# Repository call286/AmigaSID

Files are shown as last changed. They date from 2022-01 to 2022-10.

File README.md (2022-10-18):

# AmigaSID Zorro II card

Board Render Front           |  Board Render Back
:-------------------------:|:-------------------------:
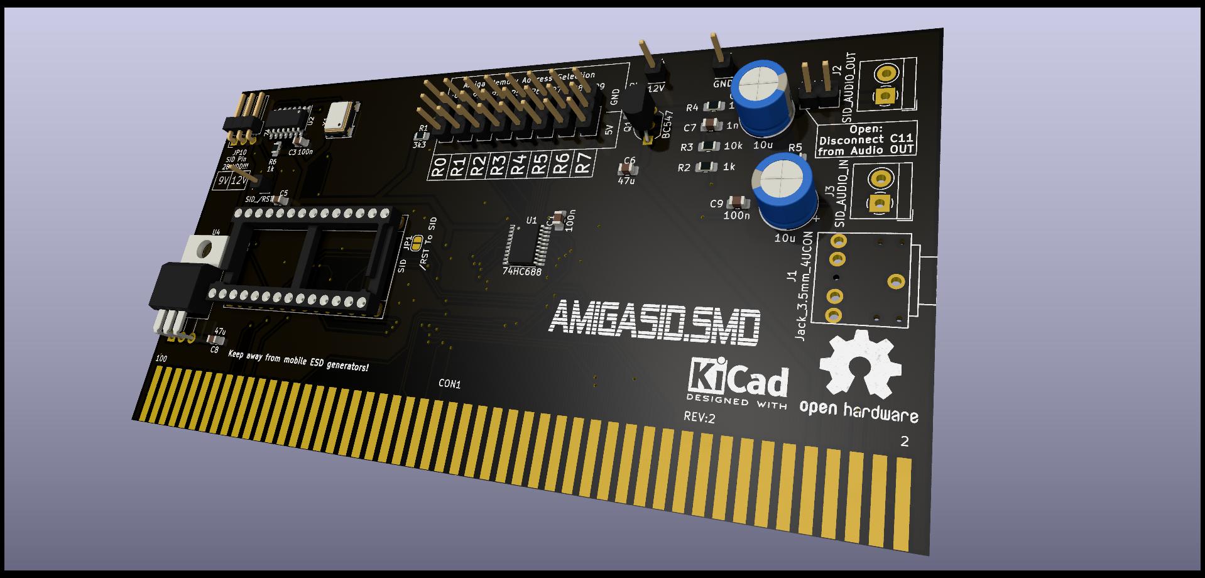
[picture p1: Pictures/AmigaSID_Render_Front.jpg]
Board Render Front
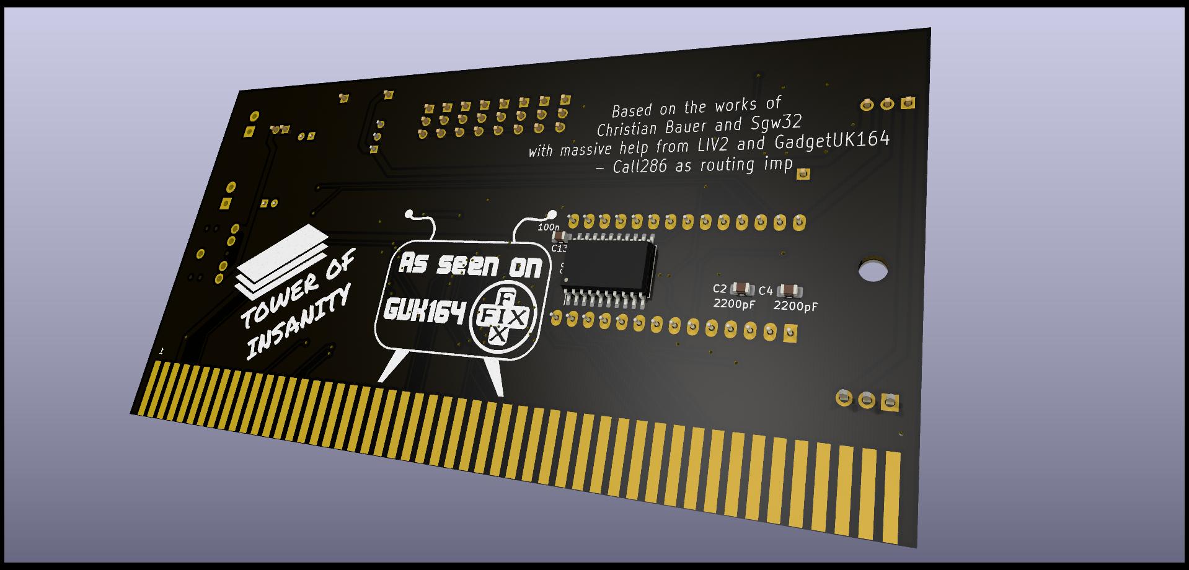
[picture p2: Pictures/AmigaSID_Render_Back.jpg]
Board Render Back
 | 

[Schematic PDF](Hardware/AmigaSID-schematic.pdf)

Forked from https://github.com/Sgw32/AmigaSID which forked from http://www.amibay.com/showthread.php?108629-Amiga-SID-player-for-Zorro-slot

Can't find the original thread on Amibay sadly, so i can't do full credits here.

## Changes

- Changed most of the components to SMD, major rerouting.
- Added 100k pull down resistor and 470pF capacitor to EXT_IN of SID like pointed out at the original schematics.
- Added 245 buffer to D0-D7 databus lines.
- Changed crystal to 7050 part.
- Tied Amiga /RST to RST of SID via solderjumper (default connected)
  - can be removed with a cut and be used at A4k with it's power LED connected to H1
- Added 8 jumpers (JP2-JP9) to set the memory address the SID can be accessed from the player side (needs patched player to use that address)
- Added filter caps to vcc lines of the IC's
- Changed audio connector to a more common type
- Moved filter caps closer to IC's
- Added logo
- Floating 74LS00 inputs tied to VCC
- Flipped polarity on C10 (SID_AUDIO_IN)
- Added jumper to disconnect audio out cap from output pins
  - instead you now can fit a little amp board like shown Gadgets video about the original version of the card
  - also added one GND and one 12V pin for powering the amp

Thanks to [LIV2](https://github.com/LIV2) and [GadgetUK](https://www.youtube.com/channel/UCRBWJ9JeJ3Q8ssn_ibii-Cg) for the help in this project.

Use at your own risk!!!
~~As of now (06.01.2021) i haven't tested that, not even ordered boards!~~
Boards were kindly provided by SparxUK - Thanks mate!
The boards worked fine on my A500 with a Zorro2 adapter and a NanoSwinSID.

## Jumper setting

The bank of jumpers on top of the card (JP2-JP9) is used to set the memory address used by the card and the players.

Jumper setting for EE range:

| Jumper  | Setting |
| :---:|:---: |
| JP2 |  1-2 (LOW) |
| JP3 |  2-3 (HIGH)  |
| JP4 |  2-3 (HIGH)  |
| JP5 |  2-3 (HIGH)  |
| JP6 |  1-2 (LOW) |
| JP7 |  2-3 (HIGH)  |
| JP8 |  2-3 (HIGH)  |
| JP9 |  2-3 (HIGH)  |

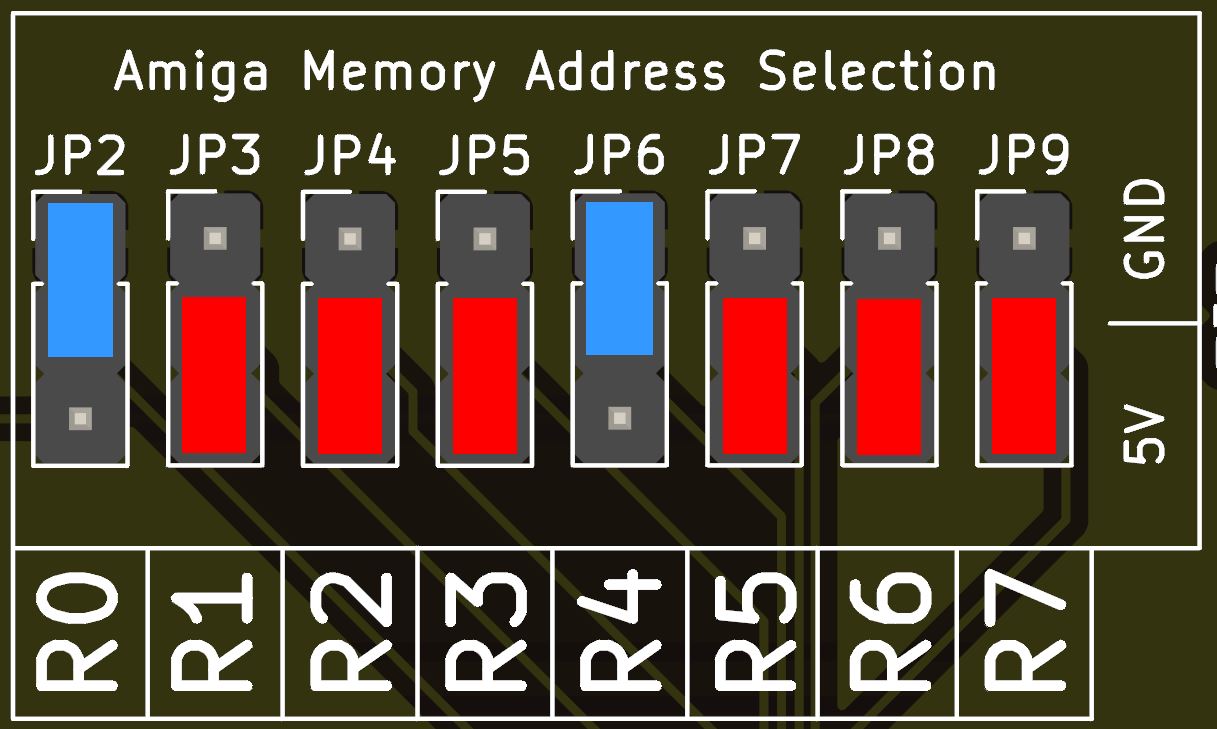
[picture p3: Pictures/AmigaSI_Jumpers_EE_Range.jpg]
Jumper Settings EE Range


## Folder: Hardware

Here you'll find the KiCAD6 project for the board.
Also there is a HTML BOM for parts placement and a jlcpcb folder with gerbers and BOM/POS for assembly (only the SMD caps/resistors, no ic's or THT parts!)

## Folder: Software

Here you'll find patched versions of players to use on the Amiga.

## TODO
- Add more/better documentation
- ~~Test the Hardware, order boards~~
  - Boards were kindly provided by SparxUK

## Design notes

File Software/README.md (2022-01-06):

# Software Section

Here you'll find modified players to use in combination with the AmigaSID Board.

## C64SID

Copy the C64SID_XX to the "players" folder of Delitracker.
Needs to be renamed as C64SID.

- [C64SID_EE](C64SID_EE)
  - Modified by LIV2 and GadgetUK164 to use the EE address range, set jumpers on the AmigaSID board accordingly.
  
## Frodo

Frodo may need a powerful system to run

- [Frodo_EE](Frodo_EE)
  - Modified by LIV2 to use EE address range

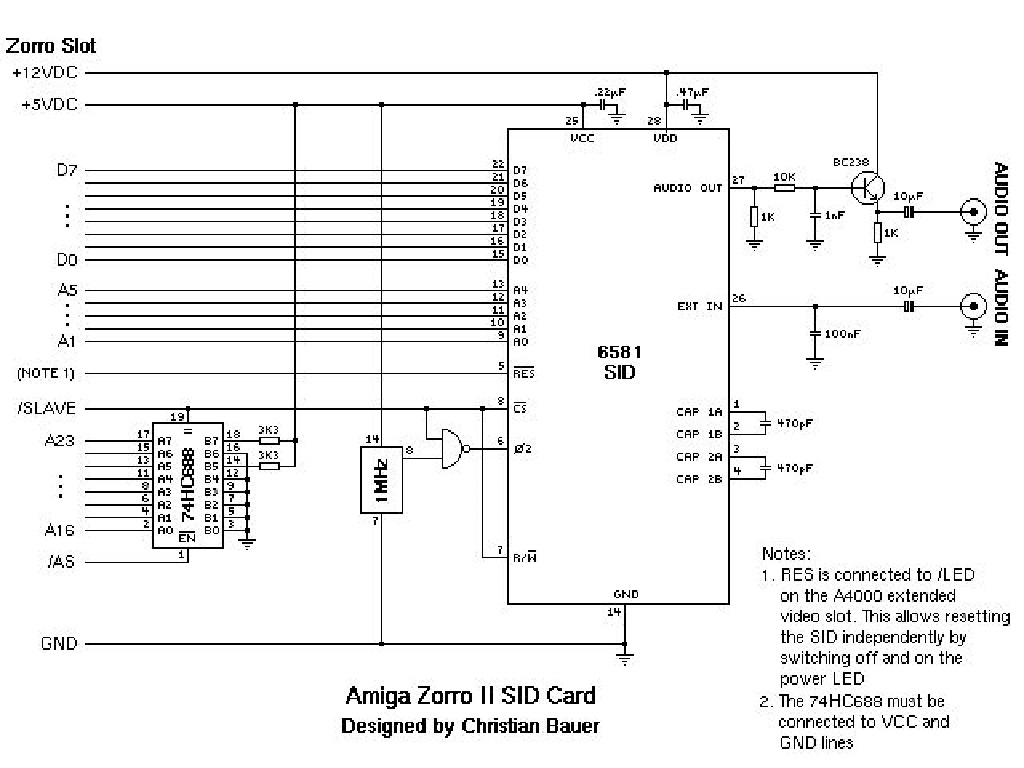
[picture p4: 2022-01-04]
Hardware/original/schematic.jpg

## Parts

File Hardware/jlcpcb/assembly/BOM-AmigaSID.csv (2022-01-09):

Comment | Designator | Footprint | LCSC
100k | R5 | R_0805_2012Metric_Pad1.20x1.40mm_HandSolder | C17407
10k | R3 | R_0805_2012Metric_Pad1.20x1.40mm_HandSolder | C17414
470p | C12 | C_0805_2012Metric_Pad1.18x1.45mm_HandSolder | C1743
1k | R2,R4,R6 | R_0805_2012Metric_Pad1.20x1.40mm_HandSolder | C17513
3k3 | R1 | R_0805_2012Metric_Pad1.20x1.40mm_HandSolder | C26010
2200pF | C2,C4 | C_0805_2012Metric_Pad1.18x1.45mm_HandSolder | C28260
22u | C5 | C_0805_2012Metric_Pad1.18x1.45mm_HandSolder | C45783
1n | C7 | C_0805_2012Metric_Pad1.18x1.45mm_HandSolder | C46653
100n | C1,C13,C3,C9 | C_0805_2012Metric_Pad1.18x1.45mm_HandSolder | C49678
SID_AUDIO_OUT | J2 | TerminalBlock_4Ucon_1x02_P3.50mm_Horizontal
74LS00 | U2 | SOIC-14_3.9x8.7mm_P1.27mm
SID_/RST | H1 | PinHeader_1x01_P2.54mm_Vertical
SID_AUDIO_IN | J3 | TerminalBlock_4Ucon_1x02_P3.50mm_Horizontal
SID | U3 | DIP-28_W15.24mm_Socket_LongPads
10u | C10 | CP_Radial_D7.5mm_P2.50mm
74HC688 | U1 | TSSOP-20_4.4x6.5mm_P0.65mm
47u | C6 | C_0805_2012Metric_Pad1.18x1.45mm_HandSolder
BC547 | Q1 | TO-92_Inline_Wide
10u | C11 | CP_Radial_D7.5mm_P2.50mm
LM7809_TO220 | U4 | TO-220-3_Horizontal_TabDown
AudioJack3 | J1 | Jack_3.5mm_4UCON
12V/9V | JP10 | PinHeader_1x03_P2.54mm_Horizontal
47u | C8 | C_0805_2012Metric_Pad1.18x1.45mm_HandSolder
SG-7050CCN | X1 | Oscillator_SMD_SeikoEpson_SG8002CA-4Pin_7.0x5.0mm
JPR3 | JP5 | PinHeader_1x03_P2.54mm_Vertical
JPR7 | JP9 | PinHeader_1x03_P2.54mm_Vertical
JPR2 | JP4 | PinHeader_1x03_P2.54mm_Vertical
/RST To SID | JP1 | SolderJumper-2_P1.3mm_Bridged_RoundedPad1.0x1.5mm
JPR1 | JP3 | PinHeader_1x03_P2.54mm_Vertical
JPR4 | JP6 | PinHeader_1x03_P2.54mm_Vertical
JPR6 | JP8 | PinHeader_1x03_P2.54mm_Vertical
JPR0 | JP2 | PinHeader_1x03_P2.54mm_Vertical
12V | J4 | PinHeader_1x01_P2.54mm_Vertical
JPR5 | JP7 | PinHeader_1x03_P2.54mm_Vertical
GND | J5 | PinHeader_1x01_P2.54mm_Vertical
Disconnect C11 from Audio OUT | JP11 | PinHeader_1x02_P2.54mm_Vertical
74HC245 | U5 | SOIC-20W_7.5x12.8mm_P1.27mm

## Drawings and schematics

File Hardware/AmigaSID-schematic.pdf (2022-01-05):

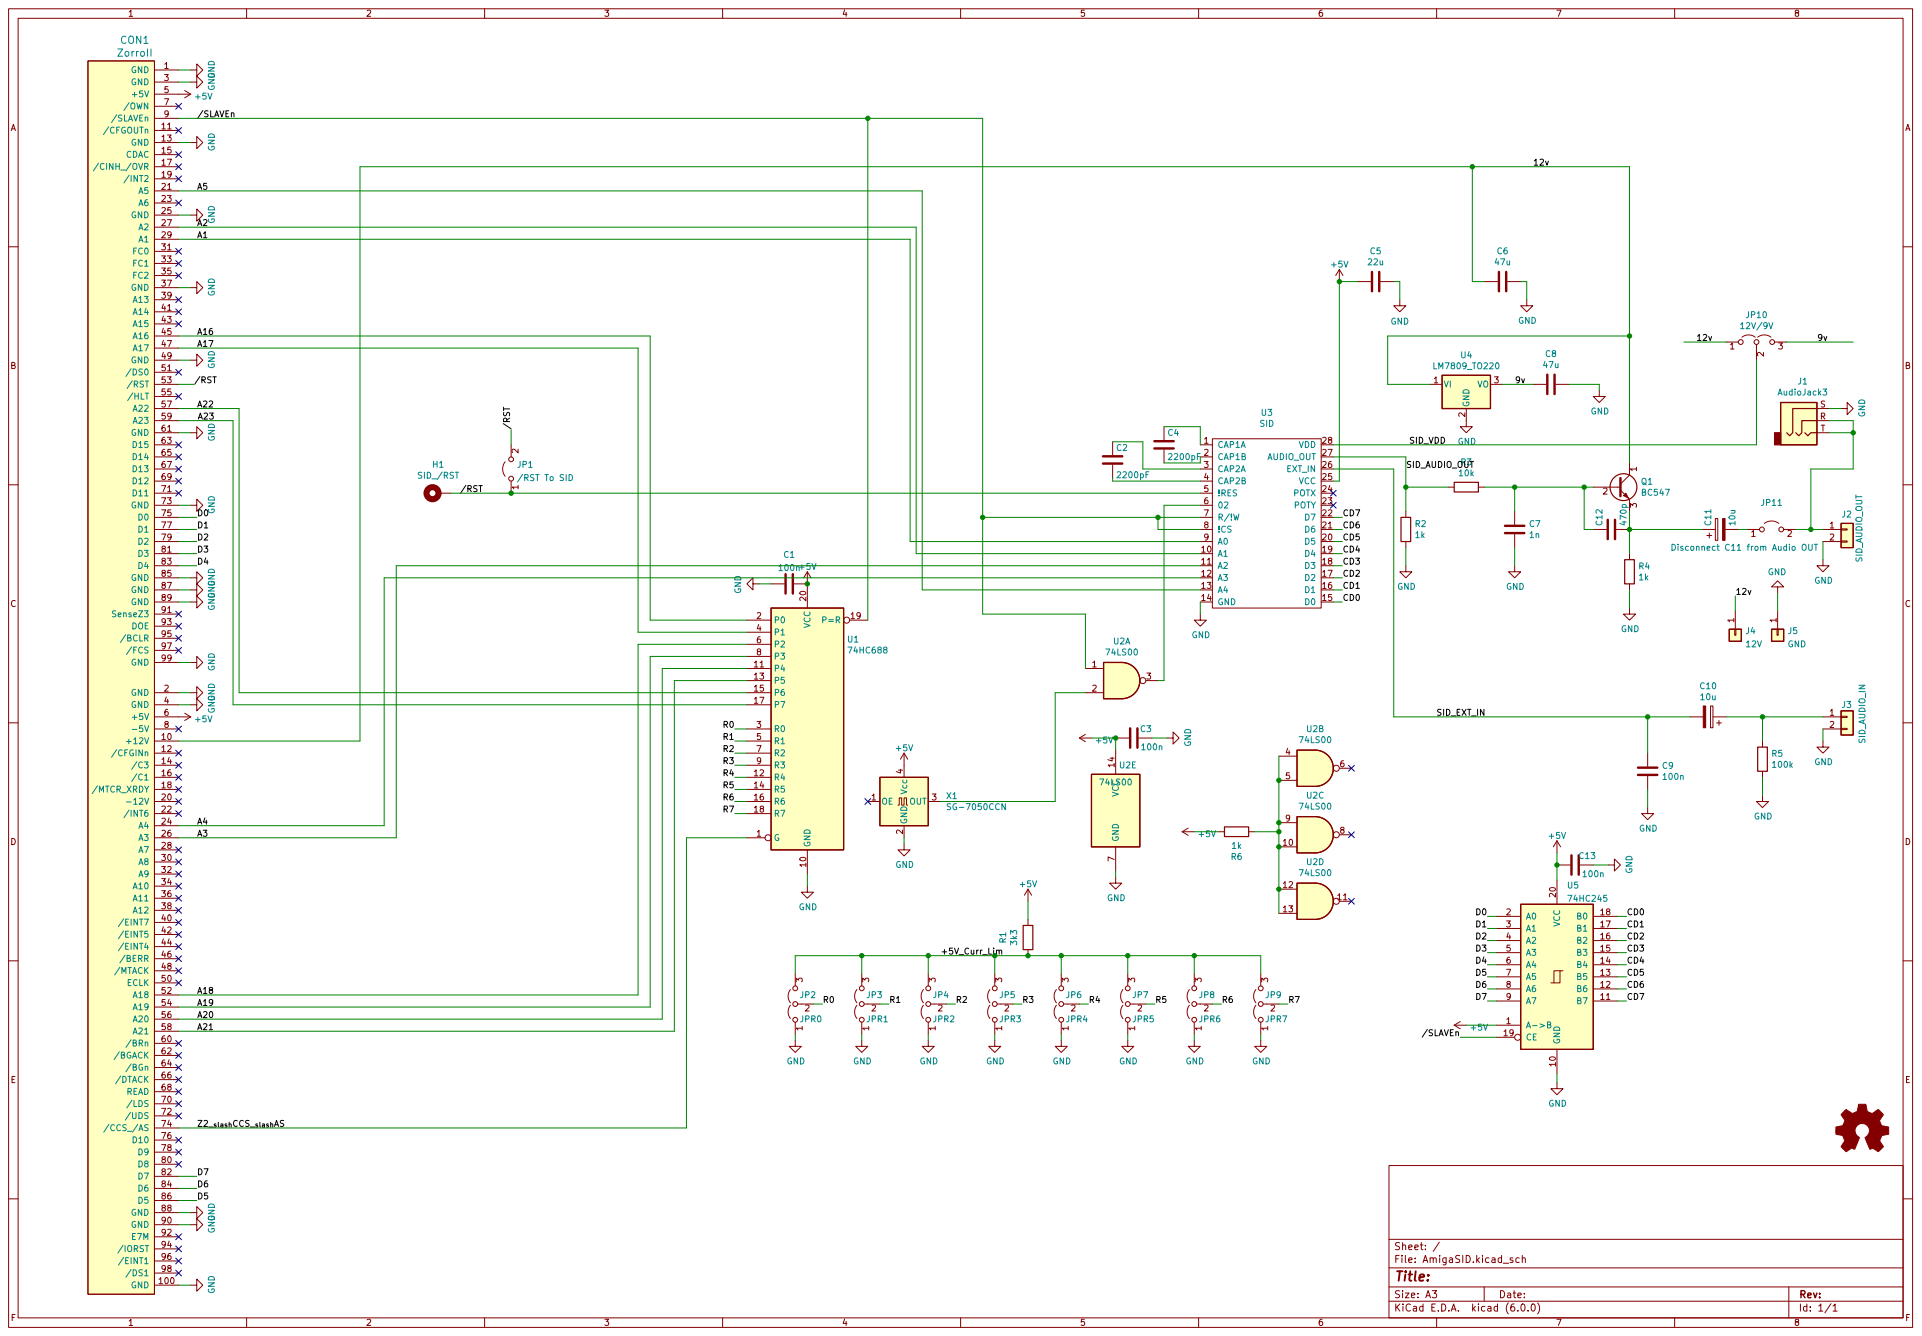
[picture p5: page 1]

+5V GND

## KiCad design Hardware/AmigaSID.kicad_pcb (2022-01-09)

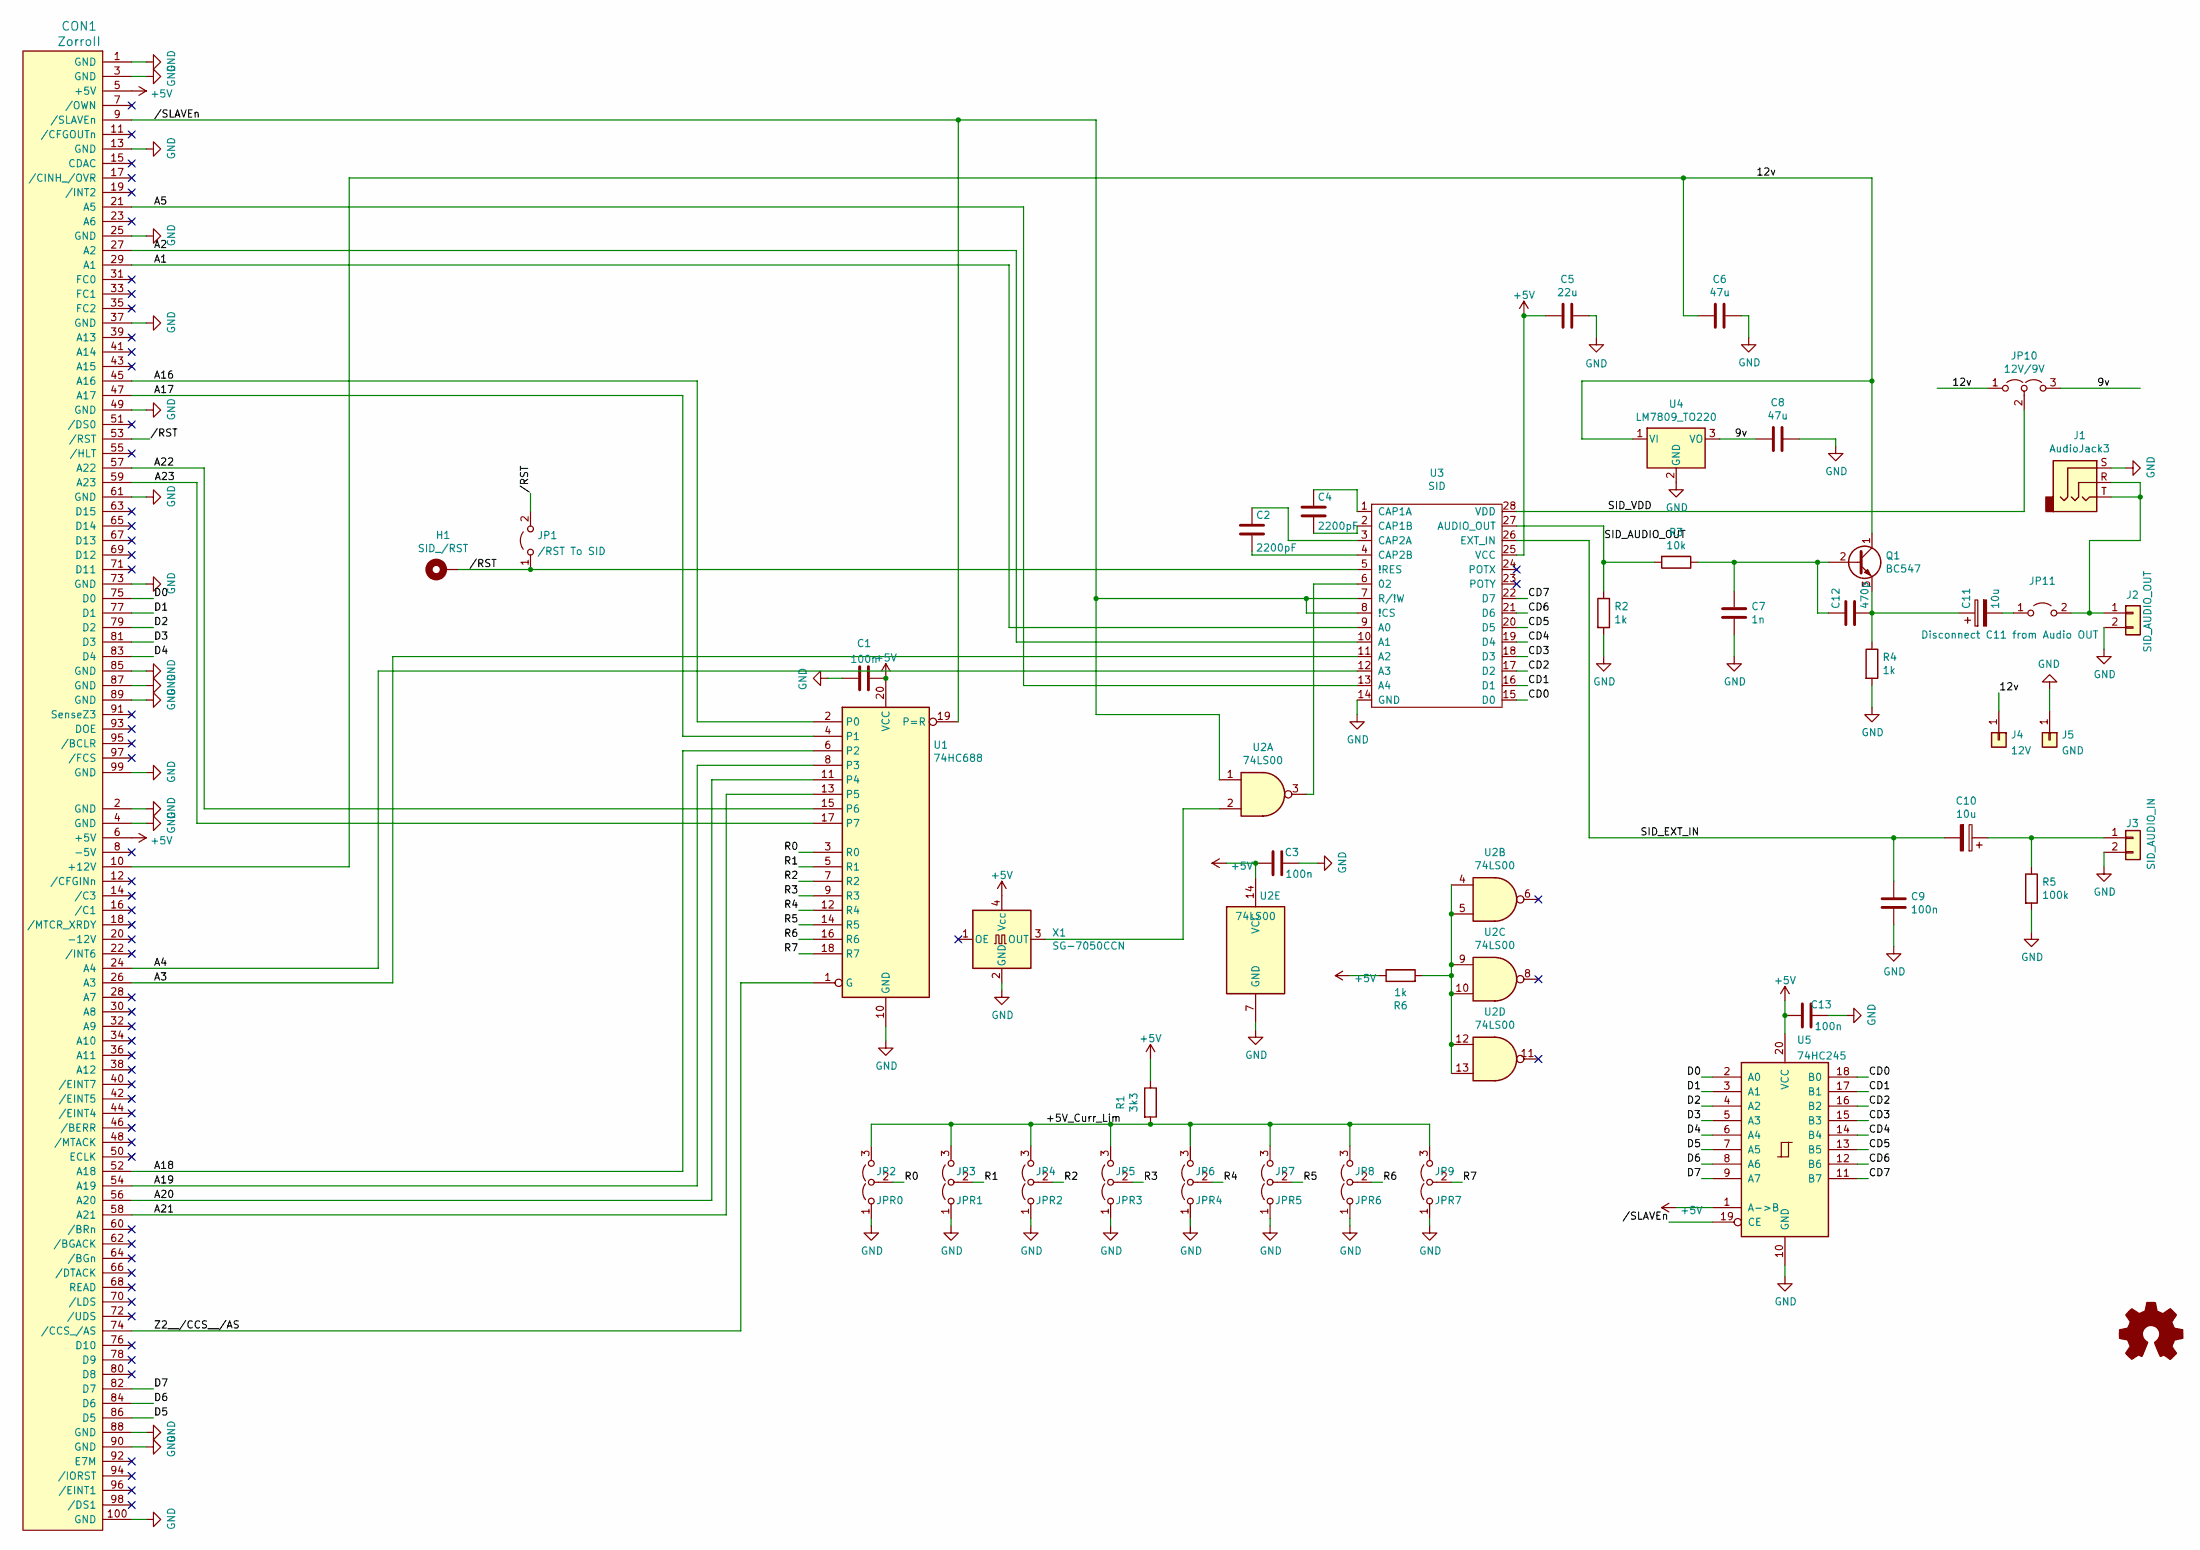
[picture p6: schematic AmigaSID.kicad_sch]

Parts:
C1, C3, C9, C13: 100n; C_0805_2012Metric_Pad1.18x1.45mm_HandSolder
C2, C4: 2200pF; C_0805_2012Metric_Pad1.18x1.45mm_HandSolder
C5: 22u; C_0805_2012Metric_Pad1.18x1.45mm_HandSolder
C6, C8: 47u; C_0805_2012Metric_Pad1.18x1.45mm_HandSolder
C7: 1n; C_0805_2012Metric_Pad1.18x1.45mm_HandSolder
C10, C11: 10u; CP_Radial_D7.5mm_P2.50mm
C12: 470p; C_0805_2012Metric_Pad1.18x1.45mm_HandSolder
CON1: ZorroII
H1: SID_/RST; PinHeader_1x01_P2.54mm_Vertical
J1: AudioJack3; Jack_3.5mm_4UCON
J2: SID_AUDIO_OUT; TerminalBlock_4Ucon_1x02_P3.50mm_Horizontal
J3: SID_AUDIO_IN; TerminalBlock_4Ucon_1x02_P3.50mm_Horizontal
J4: 12V; PinHeader_1x01_P2.54mm_Vertical
J5: GND; PinHeader_1x01_P2.54mm_Vertical
JP1: /RST To SID; SolderJumper-2_P1.3mm_Bridged_RoundedPad1.0x1.5mm
JP2: JPR0; PinHeader_1x03_P2.54mm_Vertical
JP3: JPR1; PinHeader_1x03_P2.54mm_Vertical
JP4: JPR2; PinHeader_1x03_P2.54mm_Vertical
JP5: JPR3; PinHeader_1x03_P2.54mm_Vertical
JP6: JPR4; PinHeader_1x03_P2.54mm_Vertical
JP7: JPR5; PinHeader_1x03_P2.54mm_Vertical
JP8: JPR6; PinHeader_1x03_P2.54mm_Vertical
JP9: JPR7; PinHeader_1x03_P2.54mm_Vertical
JP10: 12V/9V; PinHeader_1x03_P2.54mm_Horizontal
JP11: Disconnect C11 from Audio OUT; PinHeader_1x02_P2.54mm_Vertical
Q1: BC547; TO-92_Inline_Wide
R1: 3k3; R_0805_2012Metric_Pad1.20x1.40mm_HandSolder
R2, R4, R6: 1k; R_0805_2012Metric_Pad1.20x1.40mm_HandSolder
R3: 10k; R_0805_2012Metric_Pad1.20x1.40mm_HandSolder
R5: 100k; R_0805_2012Metric_Pad1.20x1.40mm_HandSolder
U1: 74HC688; TSSOP-20_4.4x6.5mm_P0.65mm
U2: 74LS00; SOIC-14_3.9x8.7mm_P1.27mm
U3: SID; DIP-28_W15.24mm_Socket_LongPads
U4: LM7809_TO220; TO-220-3_Horizontal_TabDown
U5: 74HC245; SOIC-20W_7.5x12.8mm_P1.27mm
X1: SG-7050CCN; Oscillator_SMD_SeikoEpson_SG8002CA-4Pin_7.0x5.0mm

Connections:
+5V: C1.1, C3.1, C5.2, C13.1, CON1.5 (+5V), CON1.6 (+5V), R1.1, R6.1, U1.20 (VCC), U2.14 (VCC), U3.25 (VCC), U5.1 (A->B), U5.20 (VCC), X1.4 (Vcc)
/9v: C8.2, JP10.3 (B), U4.3 (VO)
/12v: C6.2, CON1.10 (+12V), J4.1, JP10.1 (A), Q1.1 (C), U4.1 (VI)
/+5V_Curr_Lim: JP2.3 (B), JP3.3 (B), JP4.3 (B), JP5.3 (B), JP6.3 (B), JP7.3 (B), JP8.3 (B), JP9.3 (B), R1.2
/A1: CON1.29 (A1), U3.9 (A0)
/A2: CON1.27 (A2), U3.10 (A1)
/A3: CON1.26 (A3), U3.11 (A2)
/A4: CON1.24 (A4), U3.12 (A3)
/A5: CON1.21 (A5), U3.13 (A4)
/A16: CON1.45 (A16), U1.2 (P0)
/A17: CON1.47 (A17), U1.4 (P1)
/A18: CON1.52 (A18), U1.6 (P2)
/A19: CON1.54 (A19), U1.8 (P3)
/A20: CON1.56 (A20), U1.11 (P4)
/A21: CON1.58 (A21), U1.13 (P5)
/A22: CON1.57 (A22), U1.15 (P6)
/A23: CON1.59 (A23), U1.17 (P7)
/CD0: U3.15 (D0), U5.18 (B0)
/CD1: U3.16 (D1), U5.17 (B1)
/CD2: U3.17 (D2), U5.16 (B2)
/CD3: U3.18 (D3), U5.15 (B3)
/CD4: U3.19 (D4), U5.14 (B4)
/CD5: U3.20 (D5), U5.13 (B5)
/CD6: U3.21 (D6), U5.12 (B6)
/CD7: U3.22 (D7), U5.11 (B7)
/D0: CON1.75 (D0), U5.2 (A0)
/D1: CON1.77 (D1), U5.3 (A1)
/D2: CON1.79 (D2), U5.4 (A2)
/D3: CON1.81 (D3), U5.5 (A3)
/D4: CON1.83 (D4), U5.6 (A4)
/D5: CON1.86 (D5), U5.7 (A5)
/D6: CON1.84 (D6), U5.8 (A6)
/D7: CON1.82 (D7), U5.9 (A7)
/R0: JP2.2 (C), U1.3 (R0)
/R1: JP3.2 (C), U1.5 (R1)
/R2: JP4.2 (C), U1.7 (R2)
/R3: JP5.2 (C), U1.9 (R3)
/R4: JP6.2 (C), U1.12 (R4)
/R5: JP7.2 (C), U1.14 (R5)
/R6: JP8.2 (C), U1.16 (R6)
/R7: JP9.2 (C), U1.18 (R7)
/SID_AUDIO_OUT: R2.1, R3.2, U3.27 (AUDIO_OUT)
/SID_EXT_IN: C9.1, C10.2, U3.26 (EXT_IN)
/SID_VDD: JP10.2 (C), U3.28 (VDD)
/Z2__/CCS__/AS: CON1.74 (/CCS_/AS), U1.1 (G)
//RST: CON1.53 (/RST), H1.1, JP1.1 (A), JP1.2 (B), U3.5 (!RES)
//SLAVEn: CON1.9 (/SLAVEn), U1.19 (P=R), U2.1, U3.7 (R/!W), U3.8 (!CS), U5.19 (CE)
GND: C1.2, C3.2, C5.1, C6.1, C7.2, C8.1, C9.2, C13.2, CON1.1 (GND), CON1.2 (GND), CON1.3 (GND), CON1.4 (GND), CON1.13 (GND), CON1.25 (GND), CON1.37 (GND), CON1.49 (GND), CON1.61 (GND), CON1.73 (GND), CON1.85 (GND), CON1.87 (GND), CON1.88 (GND), CON1.89 (GND), CON1.90 (GND), CON1.99 (GND), CON1.100 (GND), J1.S, J2.2, J3.2, J5.1, JP2.1 (A), JP3.1 (A), JP4.1 (A), JP5.1 (A), JP6.1 (A), JP7.1 (A), JP8.1 (A), JP9.1 (A), R2.2, R4.2, R5.2, U1.10 (GND), U2.7 (GND), U3.14 (GND), U4.2 (GND), U5.10 (GND), X1.2 (GND)
unnamed: C2.1, U3.3 (CAP2A)
unnamed: C2.2, U3.4 (CAP2B)
unnamed: C4.1, U3.1 (CAP1A)
unnamed: C4.2, U3.2 (CAP1B)
unnamed: C10.1, J3.1, R5.1
unnamed: C11.1, C12.2, Q1.3 (E), R4.1
unnamed: C11.2, JP11.1 (A)
unnamed: C7.1, C12.1, Q1.2 (B), R3.1
unnamed: J1.R, J1.T, J2.1, JP11.2 (B)
unnamed: R6.2, U2.4, U2.5, U2.9, U2.10, U2.12, U2.13
unnamed: U2.2, X1.3 (OUT)
unnamed: U2.3, U3.6 (02)

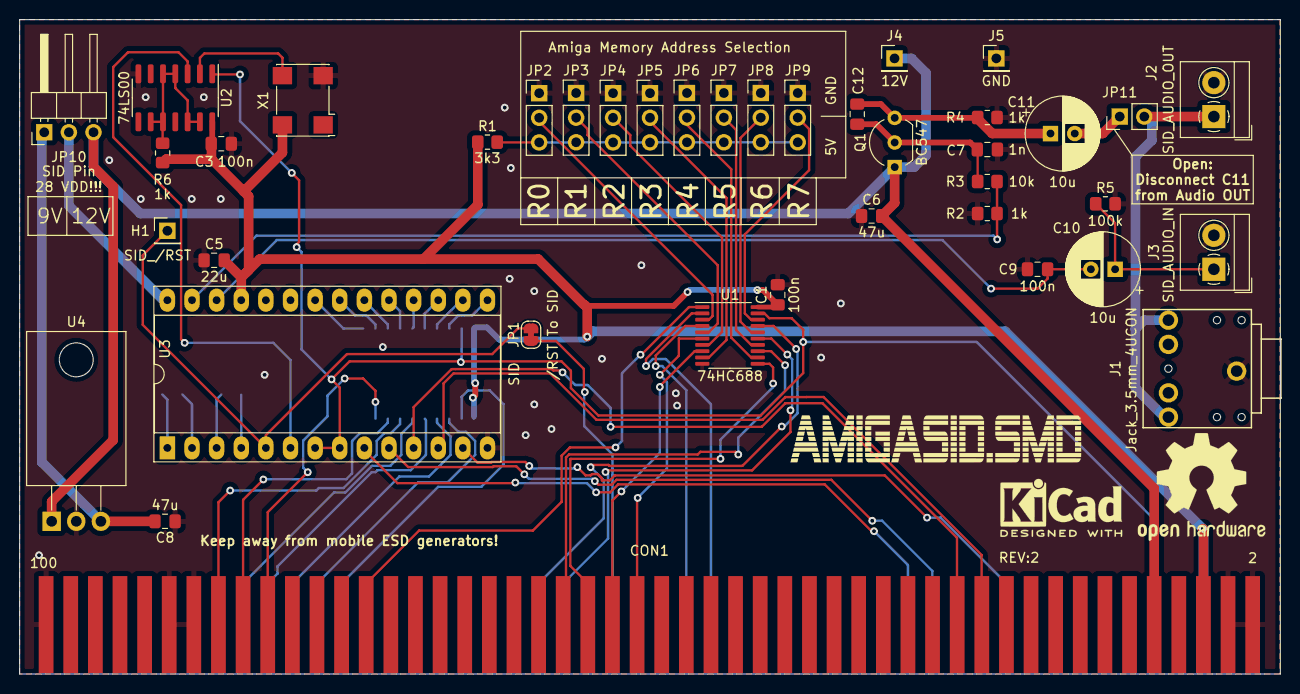
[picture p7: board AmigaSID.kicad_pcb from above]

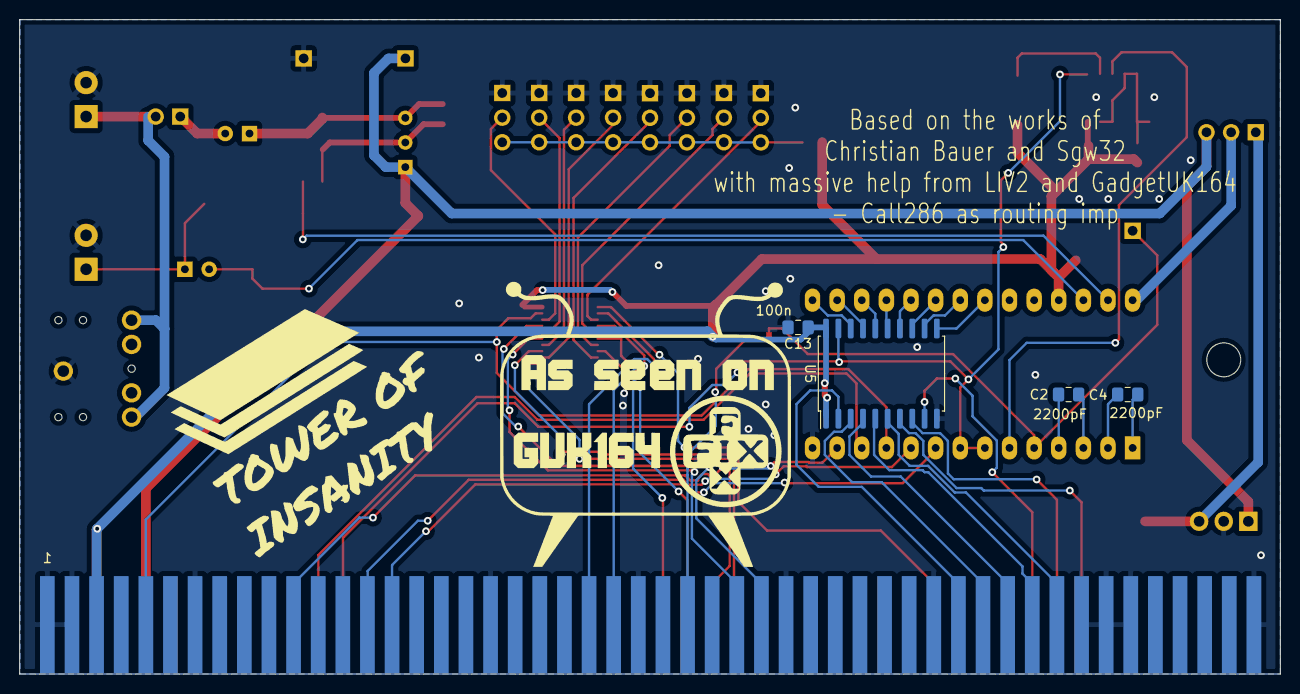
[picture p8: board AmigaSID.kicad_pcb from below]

Board: 2 copper layers, 130.0 x 67.5 mm, 44 parts (4 on the bottom side), 60 nets.

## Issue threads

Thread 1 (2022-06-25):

Speaker / Earphone line missing current limiting resistor

call286, 2022-06-25:

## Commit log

2022-01-04 * Rev1
    - changed to SMD
    - reroute
    - jumpers for address selection
    - 245 buffer added to D0-D7
    - changed audio connector
    - filter caps
    [AmigaSID.kicad_pcb, AmigaSID.kicad_sch]
2022-01-04 - Moved filter caps closer to IC's - Added logo - Floating 245 inputs tied to VCC - Flipped polarity on C10 (SID_AUDIO_IN) - Added jumper to disconnect audio out cap from output pins - instead you no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
    [AmigaSID.kicad_pcb, AmigaSID.kicad_sch]
2022-01-05 Added Schematic PDF, linked in README.md Added Renders to README.md
2022-01-06 added jlcpcb gerbers/pos/bom, html bom, modified software players updated README.md
    [AmigaSID.kicad_pcb, BOM-AmigaSID.csv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]
2022-01-09 Rev2, moved LDO, reset pin for A4k LED and voltage selection jumper, used only basic parts in JLCPCB bom
    [BOM-AmigaSID.csv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]
